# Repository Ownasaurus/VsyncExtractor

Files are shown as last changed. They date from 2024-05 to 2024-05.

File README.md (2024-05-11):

# VsyncExtractor
Designed to detect and output a simple vsync signal out of various video signals

Currently a work in progress; actively developing for  DVI/HDMI video protocol at the moment

Synthesizes using `prjtrellis (yosys + nextpnr for EPC5)` for use on an `LFE5UM5G-85F-EVN`

Modify `Makefile` to contain the path to your trellis install

`make` to build

`make flash` for flashing the firmware onto the SPI flash for permanant memory

`make test` for flashing the bitstream in volatile memory

Requires `openFPGALoader` for flashing

Supports TAS playback using the same serial protocol as the [TAStm32](https://github.com/Ownasaurus/TAStm32)
Also supports controller passthrough

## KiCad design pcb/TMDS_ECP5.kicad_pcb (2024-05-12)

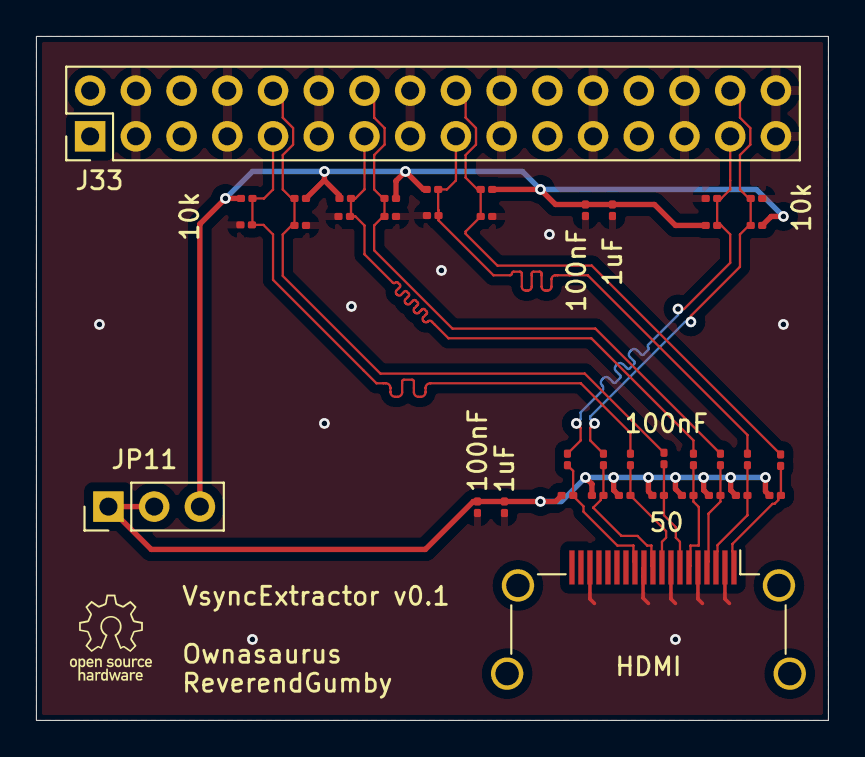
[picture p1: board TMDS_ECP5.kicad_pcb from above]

Board: 4 copper layers, 44.0 x 38.0 mm, 39 parts (0 on the bottom side), 19 nets.

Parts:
1uF: 1u; C_0201_0603Metric
10k: 10k; R_0201_0603Metric
50: 50; R_0201_0603Metric
100nF, 100nF#2: 100n; C_0201_0603Metric
C1, C2, C3, C4, C5, C6, C7: 100n; C_0201_0603Metric
C11: 100nF; C_0201_0603Metric
C12: 1uF; C_0201_0603Metric
HDMI: HDMI_A_1.4; HDMI_A_Amphenol_10029449-x01xLF_Horizontal
J33: Conn_02x16_Odd_Even; PinHeader_2x16_P2.54mm_Vertical
JP11: Conn_01x03; PinHeader_1x03_P2.54mm_Vertical
R1, R2, R3, R5, R6, R7, R8, R9, R10, R11, R12, R13, R14, R15, R16: 10k; R_0201_0603Metric
R18, R19, R20, R21, R22, R23, R24: 50; R_0201_0603Metric

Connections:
+2V5: 1uF.2, 100nF#2.2, JP11.3, R1.1, R3.1, R5.1, R7.1, R9.1, R11.1, R13.1, R15.1
+3V3: 50.2, C11.2, C12.2, JP11.1, JP11.2, R18.2, R19.2, R20.2, R21.2, R22.2, R23.2, R24.2
/clk_1v25_N: C1.2, J33.29, R1.2, R2.1
/clk_1v25_P: 10k.1, C2.2, J33.30, R3.2
/clk_3v3_N: 50.1, C1.1, HDMI.12 (CK-)
/clk_3v3_P: C2.1, HDMI.10 (CK+), R18.1
/d0_1v25_N: C3.2, J33.9, R5.2, R6.1
/d0_1v25_P: C4.2, J33.10, R7.2, R8.1
/d0_3v3_N: C3.1, HDMI.9 (D0-), R19.1
/d0_3v3_P: C4.1, HDMI.7 (D0+), R20.1
/d1_1v25_N: C5.2, J33.13, R9.2, R10.1
/d1_1v25_P: C6.2, J33.14, R11.2, R12.1
/d1_3v3_N: C5.1, HDMI.6 (D1-), R21.1
/d1_3v3_P: C6.1, HDMI.4 (D1+), R22.1
/d2_1v25_N: C7.2, J33.17, R13.2, R14.1
/d2_1v25_P: 100nF.2, J33.18, R15.2, R16.1
/d2_3v3_N: C7.1, HDMI.3 (D2-), R23.1
/d2_3v3_P: 100nF.1, HDMI.1 (D2+), R24.1
GND: 1uF.1, 10k.2, 100nF#2.1, C11.1, C12.1, HDMI.2 (D2S), HDMI.5 (D1S), HDMI.8 (D0S), HDMI.11 (CKS), HDMI.17 (GND), J33.3, J33.4, J33.7, J33.8, J33.11, J33.12, J33.15, J33.16, J33.19, J33.20, J33.23, J33.24, J33.27, J33.28, J33.31, J33.32, R2.2, R6.2, R8.2, R10.2, R12.2, R14.2, R16.2

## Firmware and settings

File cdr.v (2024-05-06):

//Ownasaurus

`default_nettype none
module clock_and_data_recovery(input tmds_data, input bit_clk, output reg [9:0] tmds_word, output valid_data);

localparam STATE_INITIAL = 0;
localparam STATE_PHASE_ALIGNED = 1;
localparam STATE_WORD_ALIGNED = 2;

reg [1:0] state = 2'b00;
reg [2:0] substate = 3'd0;

reg [1:0] vals = 2'b00;
reg [19:0] word_buffer = 20'b00000000000000000000;

wire [3:0] token_offset;
reg [3:0] word_offset; // defining d15 as undefined
reg [4:0] shifts_since_eye_open = 5'd0;

localparam WORD_COUNT_LIMIT = 1200;
reg [4:0] counter = 5'b00000;
reg [10:0] word_count = 11'd0; // max 2048, which is well above 1080p + control tokens, which is max supported resolution
reg [4:0] consecutive_token_count = 5'd0;
reg attempt_number = 1'b0;

IDDRX1F twofer(.D(tmds_data), .SCLK(bit_clk), .RST(), .Q0(vals[0]), .Q1(vals[1]));

token_detector td(.buffer(word_buffer), .token_loc(token_offset));

assign valid_data = (word_offset == 4'd15) ? 1'b0 : 1'b1; // data is valid iff our offset is defined

// always shift the two latest values into the word_buffer per bit_clk cycle
always @(posedge bit_clk) begin
    word_buffer <= {vals[1:0], word_buffer[19:2]};

    // keep track of every 5 cycles
    if(counter == 5'b10000) begin
        counter <= 5'b00001;
    end
    else if(counter == 5'b00000) begin // special case to skip first iteration
        counter <= 5'b00010;
    end
    else begin
        counter <= (counter << 1);
    end

    // process the word logic once every word aka 5 cycles
    if(counter == 5'b00001) begin
        if(state == STATE_INITIAL) begin
            // if timeout period, assume we're in jitter
            // if find control token before timeout period, assume we're somewhere in the eye
            // let timeout period be based on word count, let's say 1200 words

            // determine if we are in jitter or not
            if(consecutive_token_count >= 12) begin // conclude not in jitter!
                // logic depending on where in algorithm we are
                // TODO: center the eye nicely
                // for now, just move on to the next phase and reset initial variables
                state <= STATE_PHASE_ALIGNED;
                word_count <= 0;
                consecutive_token_count <= 0;
                attempt_number <= 0;
            end
            else if(token_offset != 4'd15) begin // not undefined means we found a token!
                consecutive_token_count <= consecutive_token_count + 1;

            end
            else begin // not a token
                word_count <= word_count + 1;

                // check for two failure cases that indicate we're in jitter
                // 1) we broke a streak prematurely
                // 2) we've gone too many words without seeing a token
                if(consecutive_token_count > 0 || word_count >= WORD_COUNT_LIMIT) begin
                    if(attempt_number == 0) begin // first attempt means we can reset
                        consecutive_token_count <= 5'd0; //
                    end
                    else begin // second attempt means we should change phase and reset state
                        // signal to PLL to change
                        // wait enough cycles
                        // resume with a reset state
                    end
                end
            end

            // Logic:
            // 0. (only if in eye) advance towards jitter
            // 1. we are in jitter
            // 2. advance clock phase until we are no longer in jitter. record phase offset as O1
            // 3. advance clock phase slowly until we are in jitter again. record phase offset as O2
            // 4. set clock phase to the average of O1 and O2
            // 5. we are now in the center of the eye
            // Source: Xilinx xapp460
            
        end
        else if(state == STATE_PHASE_ALIGNED) begin
            // need to align to word boundaries
            if(token_offset != 4'd15) begin // not undefined means we found a token!
                word_offset <= token_offset; // save the offset
                state <= STATE_WORD_ALIGNED; // not we are aligned
            end
        end
        else if(state == STATE_WORD_ALIGNED) begin
            // assign tmds_word based on the word boundary
            case(word_offset)
                4'd0: tmds_word <= word_buffer[9:0];
                4'd1: tmds_word <= word_buffer[10:1];
                4'd2: tmds_word <= word_buffer[11:2];
                4'd3: tmds_word <= word_buffer[12:3];
                4'd4: tmds_word <= word_buffer[13:4];
                4'd5: tmds_word <= word_buffer[14:5];
                4'd6: tmds_word <= word_buffer[15:6];
                4'd7: tmds_word <= word_buffer[16:7];
                4'd8: tmds_word <= word_buffer[17:8];
                4'd9: tmds_word <= word_buffer[18:9];
                default: tmds_word <= 10'b1111111111; // undefined state
            endcase
        end
    end
end

endmodule

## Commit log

2024-05-10 initial pcb commit
    [TMDS_ECP5.kicad_pcb, TMDS_ECP5.kicad_sch]
2024-05-10 revised pcb layout
    [TMDS_ECP5.kicad_pcb, TMDS_ECP5.kicad_sch]
2024-05-11 length matching
    [TMDS_ECP5.kicad_pcb]
2024-05-11 silk screen cleanup
    [TMDS_ECP5.kicad_pcb]
2024-05-12 clean silkscren; trace repair; DRC pass
    [TMDS_ECP5.kicad_pcb]
